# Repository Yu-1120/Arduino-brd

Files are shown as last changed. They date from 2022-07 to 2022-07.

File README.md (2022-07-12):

# arduino_brd
arduino的最小板
**描述：**

1.接口改为Type-C。

2.增加二极管，防止反接。

3.AMS1117-5,0用来稳压整个电路。（压降有点大）

4.串口采用CH340N（自带晶振，相当于缩小版的CH340C）

5.电源，RX，TX，D13灯全部满足。

6.去除了ICSP方便烧录，采用引脚进行ICSP烧录。

7.增加了3.3v LOD稳压芯片，外围一共有3个3.3v/5v接口，方便接入更多的传感器。

8.所有引脚全部引出，方便后续使用。

**不足：**

AMS11175.0压降比较大，5v输出不到5v，可以采用稳压二极管（需要自行更改吧）

填坑专区

1.复位电路中一定要增加个100nF接在RESET上，不然不可能上传成功的！！！！



2.实际在测试当中有的方案采用CH340C，DTR和RTS没啥区别，而且CH340C接口多，产生了浪费还占地方

所以本工程采用CH340N一样的可以愉快的烧录，占地小，何乐而不为呢？

新手建议：

如果使用CH430C方案，供电的5V的话，需要吧V3引脚接地哦！

3.3V供电的方案那就吧V3接在VCC（3.3V）上。



3.要想完美的使用Type-C,必须让电脑识别C To C协议，所以两个5.1K的电阻必不可少哦！！



**成品图：**

**正面**


**反面**

国产版和CCNANO对比图

丝印放在外面，大了一圈


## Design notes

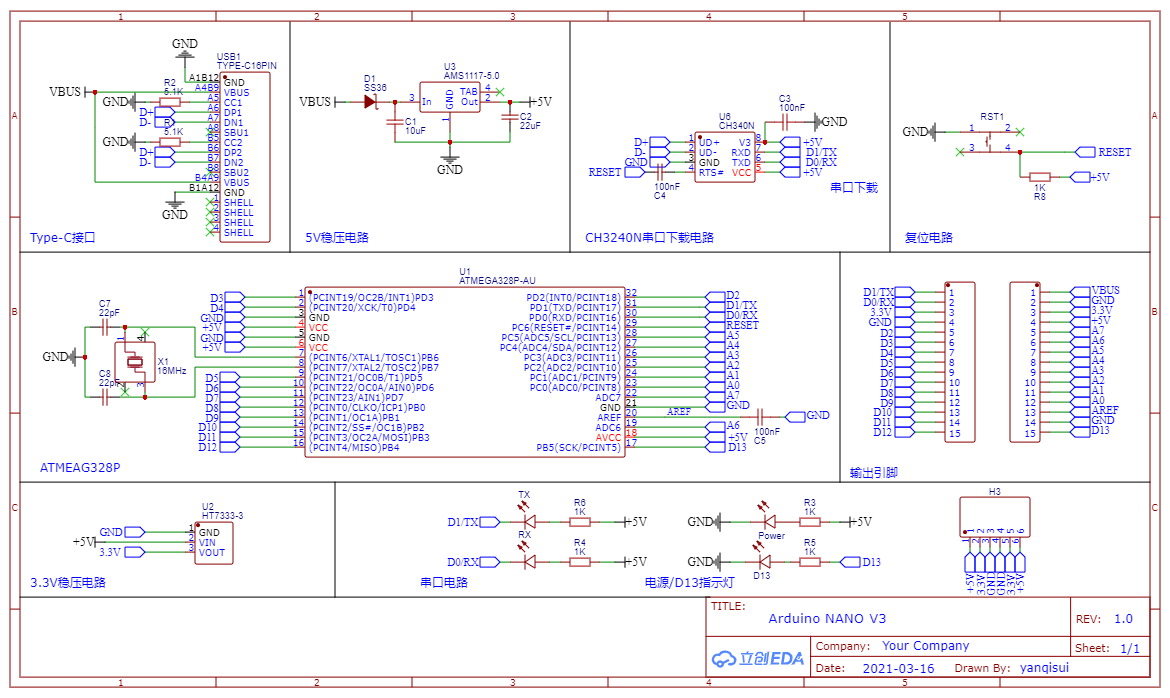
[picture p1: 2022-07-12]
Schematic_(已验证) Arduino NANO V3_2022-07-03.png

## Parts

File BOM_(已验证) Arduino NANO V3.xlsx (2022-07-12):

ID | Name | Designator | Footprint | Quantity | BOM_Supplier | BOM_Manufacturer Part | BOM_Manufacturer | BOM_Supplier Part
1 | 22pF | C8,C7 | C0603 | 2 | LCSC | CL10C220JB8NNNC | SAMSUNG | C1653
2 | 100nF | C4,C5,C3 | C0603 | 3 | LCSC | GRT188R61E106ME13D | Murata Electronics | C697423
3 | SKRPACE010 | RST1 | KEY-SMD_4P-L4.2-W3.2-P2.20-LS4.6 | 1 | LCSC | SKRPACE010 | ALPS | C139797
4 | HT7333-3 | U2 | SOT-89-3_L4.5-W2.5-P1.50-LS4.2-BR | 1 | LCSC | HT7333-3 | HOLTEK | C84207
5 | SS36 | D1 | SMA_L4.3-W2.6-LS5.2-RD | 1 | LCSC | SS36 | MDD | C16015
6 | 10uF | C1 | C0603 | 1 | LCSC | JMK107ABJ106KA-T | Taiyo Yuden | C319196
7 | CH340N | U6 | SOP-8_L5.0-W4.0-P1.27-LS6.0-BL | 1 | LCSC | CH340N | WCH(Jiangsu Qin Heng) | C506813
8 | 22uF | C2 | C0603 | 1 | LCSC | 06036D226MAT2A | AVX | C140720
9 | AMS1117-5.0 | U3 | SOT-223_L6.5-W3.5-P2.30-LS7.0-BR | 1 | LCSC | AMS1117-5.0 | AMS | C6187
10 | 16MHz | X1 | OSC-SMD_4P-L3.2-W2.5-BL | 1 | LCSC | X322516MLB4SI | YXC | C13738
11 | 1K | R4,R5,R8,R6,R3 | R0603 | 5 | LCSC | RMC06031K1%N | Tyohm | C269704
12 | 5.1K | R1,R2 | R0603 | 2 | LCSC | RMC06035.1K5%N | Tyohm | C269696
13 | TX | LED4 | LED0603-R-RD | 1 | LCSC | 19-213/R6W-BP2Q2B/3T | Everlight Elec | C181863
14 | RX | LED2 | LED0603-R-RD | 1 | LCSC | 19-213/R6W-BP2Q2B/3T | Everlight Elec | C181863
15 | Power | LED1 | LED0603-R-RD | 1 | LCSC | 19-213/R6W-BP2Q2B/3T | Everlight Elec | C181863
16 | D13 | LED3 | LED0603-R-RD | 1 | LCSC | 19-213/R6W-BP2Q2B/3T | Everlight Elec | C181863
17 | Header-Male-2.54_1x15 | H2,H1 | HDR-TH_15P-P2.54-V | 2 | LCSC | 210S-1*15P L=11.6MMGold-plated black | Ckmtw | C124373
18 | Z-211-0611-0021-001 | H3 | HDR-TH_6P-P2.54-V_Z-211-0611-0021-001 | 1 | LCSC | Z-211-0611-0021-001 | Nextronics Engineering | C190819
19 | TYPE-C16PIN | USB1 | USB-C-SMD_TYPE-C16PIN | 1 | LCSC | TYPE-C16PIN | SHOU HAN | C393939
20 | ATMEGA328P-AU | U1 | TQFP-32_L7.0-W7.0-P0.80-LS9.0-BL | 1 | LCSC | ATMEGA328P-AU | MICROCHIP | C14877
